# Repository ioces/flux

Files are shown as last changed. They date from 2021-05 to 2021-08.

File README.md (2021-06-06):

# Flux - a battery powered soldering station for Weller RT tips

This design is currently a work in progress, with the ultimate goal of being a portable soldering station utilising Weller RT tips. The design has two outputs, and will be powered off regular 18 or 36 V power tool lithium ion battery packs. It will support all RT tips from the RTP, RTM at RTU series.

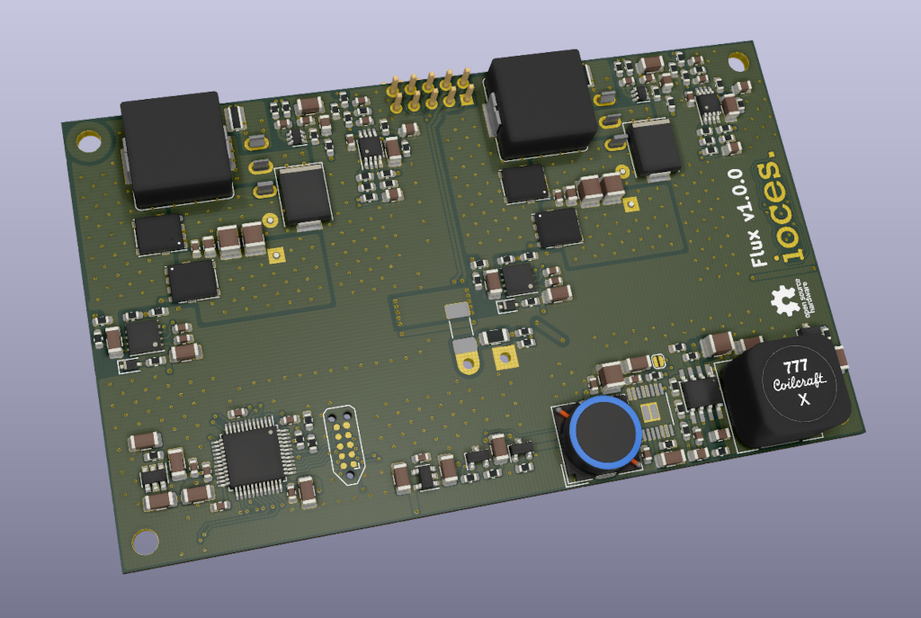
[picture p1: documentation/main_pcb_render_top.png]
Rendering of the Flux PCB from the top


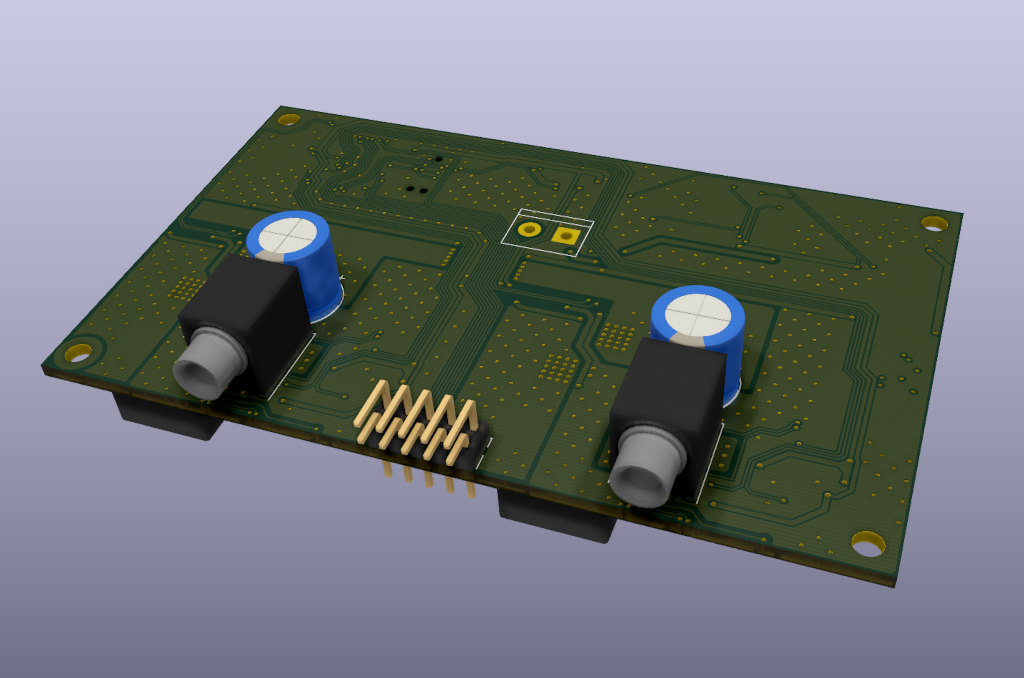
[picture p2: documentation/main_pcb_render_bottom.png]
Rendering of the Flux PCB from the bottom


## Current status

Flux is still a work in progress, and has just made it to the PCA prototyping stage:

- [x] Design
- [x] Schematic capture
- [x] PCB layout of v1.0.0
- [x] Prototype PCB/stencil ordered
- [x] BOM generation
- [x] Part ordering
- [ ] Documentation
- [ ] Prototype assembly
- [ ] Firmware development
- [ ] Prototype testing
- [ ] Enclosure design

## License

This project is licensed under two separate licenses. The hardware design and documentation for this project is licensed under the [CERN Open Hardware Licence Version 2 - Strongly Reciprocal](https://ohwr.org/cern_ohl_s_v2.txt) (CERN-OHL-S-2.0). The software and firmware source code for the project is licensed under the [GNU General Public License Version 3](https://www.gnu.org/licenses/gpl-3.0.txt) (GPL-3.0-only).

Further details can be found in the [license file](LICENSE.md).

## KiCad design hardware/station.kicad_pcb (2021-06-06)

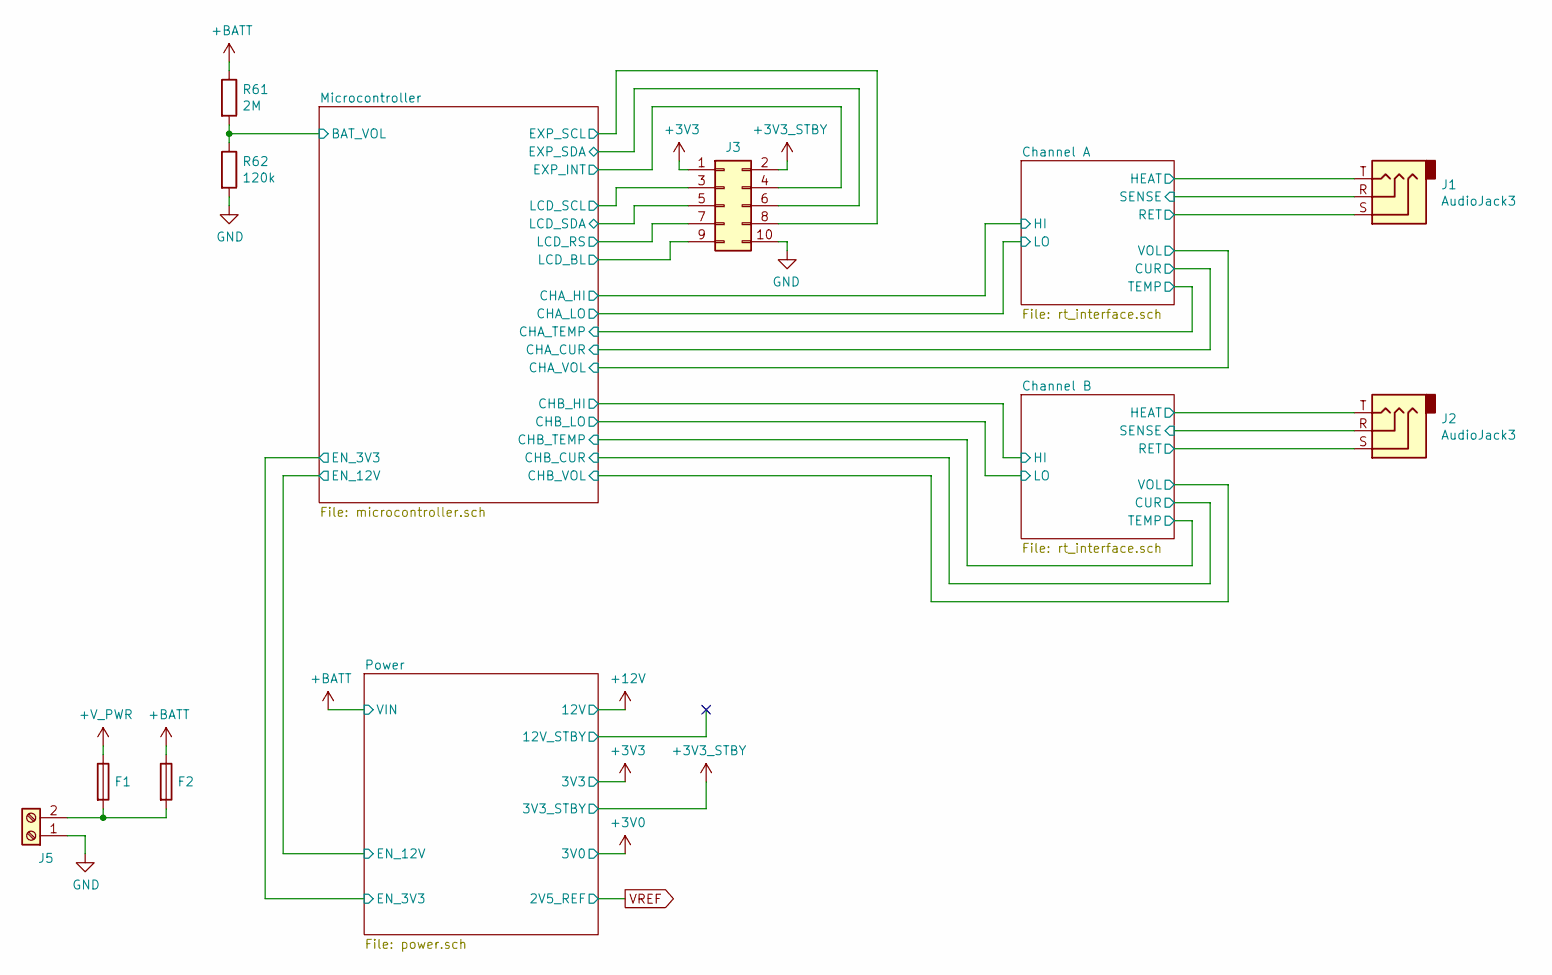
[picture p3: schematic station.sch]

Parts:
F1: Fuse; Fuse_2410; Part Number CB61F15A-TR2
F2: Fuse; Fuse_1206_3216Metric; Part Number C1F 375
J1, J2: AudioJack3; Jack_3.5mm_Adam_Tech_ASJ-125-3; Part Number ASJ-125-3
J3: Conn_02x05_Odd_Even; PinHeader_2x05_P2.54mm_BoardEdge; Part Number 10129382-910002BLF
J5: Screw_Terminal_01x02; TerminalBlock_bornier-2_P5.08mm; Part Number TB004-508-02BE
R61: 2M; R_0603_1608Metric; Tolerance 1%; Part Number ERJ-3EKF2004V
R62: 120k; R_0603_1608Metric; Tolerance 1%; Part Number RMCF0603FT120K

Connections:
+3V3: J3.1; also elsewhere on the board
+3V3_STBY: J3.2; also elsewhere on the board
+BATT: F2.1, R61.1; also elsewhere on the board
+V_PWR: F1.1; also elsewhere on the board
/Channel A/HEAT: J1.T; also elsewhere on the board
/Channel A/RET: J1.S; also elsewhere on the board
/Channel A/SENSE: J1.R; also elsewhere on the board
/Channel B/HEAT: J2.T; also elsewhere on the board
/Channel B/RET: J2.S; also elsewhere on the board
/Channel B/SENSE: J2.R; also elsewhere on the board
/Microcontroller/BAT_VOL: R61.2, R62.1; also elsewhere on the board
/Microcontroller/EXP_INT: J3.4; also elsewhere on the board
/Microcontroller/EXP_SCL: J3.8; also elsewhere on the board
/Microcontroller/EXP_SDA: J3.6; also elsewhere on the board
/Microcontroller/LCD_BL: J3.9; also elsewhere on the board
/Microcontroller/LCD_RS: J3.7; also elsewhere on the board
/Microcontroller/LCD_SCL: J3.3; also elsewhere on the board
/Microcontroller/LCD_SDA: J3.5; also elsewhere on the board
GND: J3.10, J5.1, R62.2; also elsewhere on the board
unnamed: F1.2, F2.2, J5.2

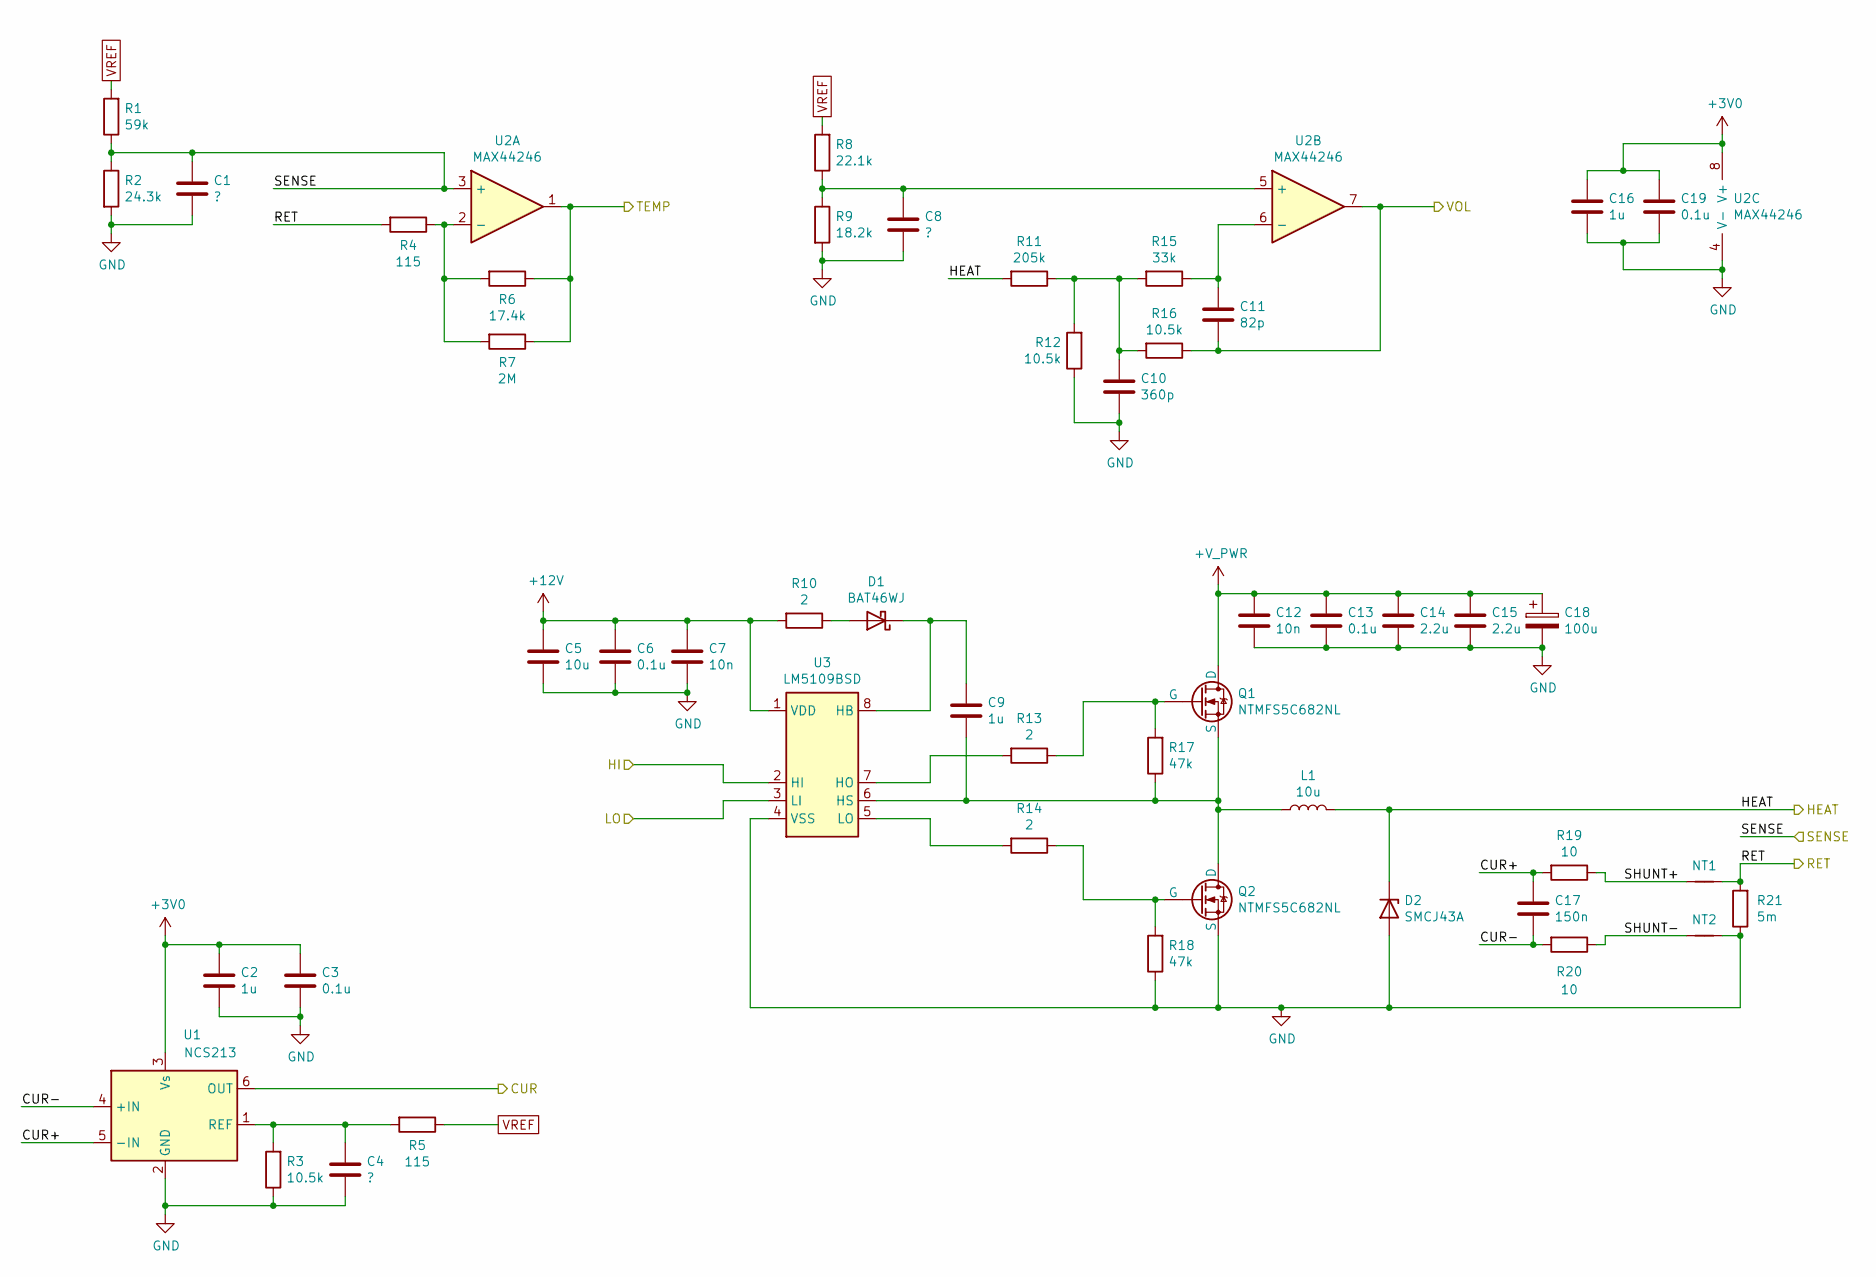
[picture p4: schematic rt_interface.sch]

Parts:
C1, C4, C8: ?; C_0805_2012Metric
C2, C9, C16: 1u; C_1206_3216Metric; Voltage Rating 25 V; Tolerance 10%; Part Number C1206C105K3RACAUTO
C3, C6, C19: 0.1u; C_0603_1608Metric; Voltage Rating 35 V; Tolerance 10%; Part Number GMK107B7104KAHT
C5: 10u; C_1206_3216Metric; Voltage Rating 35 V; Tolerance 10%; Part Number GMK316AB7106KL-TR
C7, C12: 10n; C_0603_1608Metric; Voltage Rating 100 V; Tolerance 10%; Part Number C1608X7R2A103K080AA
C10: 360p; C_0603_1608Metric; Voltage Rating 50 V; Tolerance 5%; Part Number C0603C361J5GAC7867
C11: 82p; C_0603_1608Metric; Voltage Rating 50 V; Tolerance 5%; Part Number C0603C820J5GACTU
C13: 0.1u; C_0805_2012Metric; Voltage Rating 100 V; Tolerance 10%; Part Number 885012207128
C14, C15: 2.2u; C_1210_3225Metric; Voltage Rating 100 V; Tolerance 10%; Part Number HMK325B7225KM-T
C17: 150n; C_0603_1608Metric; Voltage Rating 25 V; Tolerance 10%; Part Number 885012206072
C18: 100u; CP_Radial_D10.0mm_P5.00mm; Voltage Rating 63 V; Tolerance 20%; Part Number 63YXJ100M10X12.5
D1: BAT46WJ; D_SOD-323F; Part Number BAT46WJF
D2: SMCJ43A; D_SMC; Part Number SMCJ43A
L1: 10u; L_Bourns_SRP1265C; Part Number SRP1265C-100M
NT1, NT2: Net-Tie_2; NetTie-2_SMD_Pad0.2mm
Q1, Q2: NTMFS5C682NL; ONSemi_SO-8FL_488AA_Fill; Part Number NTMFS5C682NL
R1: 59k; R_0603_1608Metric; Tolerance 1%; Part Number RMCF0603FT59K0
R2: 24.3k; R_0603_1608Metric; Tolerance 1%; Part Number RMCF0603FT24K3
R3, R12, R16: 10.5k; R_0603_1608Metric; Tolerance 1%; Part Number RMCF0603FT10K5
R4, R5: 115; R_0603_1608Metric; Tolerance 1%; Part Number RMCF0603FT115R
R6: 17.4k; R_0603_1608Metric; Tolerance 1%; Part Number RMCF0603FT17K4
R7: 2M; R_0603_1608Metric; Tolerance 1%; Part Number ERJ-3EKF2004V
R8: 22.1k; R_0603_1608Metric; Tolerance 1%; Part Number RMCF0603FT22K1
R9: 18.2k; R_0603_1608Metric; Tolerance 1%; Part Number RMCF0603FT18K2
R10, R13, R14: 2; R_0603_1608Metric; Tolerance 5%; Part Number ERJ-PA3J2R0V
R11: 205k; R_0603_1608Metric; Tolerance 1%; Part Number RMCF0603FT205K
R15: 33k; R_0603_1608Metric; Tolerance 1%; Part Number CR0603-FX-3302ELF
R17, R18: 47k; R_0603_1608Metric; Tolerance 5%; Part Number CR0603-JW-473ELF
R19, R20: 10; R_0603_1608Metric; Tolerance 1%; Part Number CR0603-FX-10R0ELF
R21: 5m; R_0612_1632Metric; Tolerance 1%; Part Number CSRF0612FT5L00
U1: NCS213; SOT-363_SC-70-6; Part Number NCS213RSQT2G
U2: MAX44246; MSOP-8_3x3mm_P0.65mm; Part Number MAX44246AUA+
U3: LM5109BSD; WSON-8_4x4mm_P0.8mm; Part Number LM5109BSD/NOPB

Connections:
+3V0: C2.1, C3.1, C16.1, C19.1, U1.3 (Vs), U2.8 (V+); also elsewhere on the board
+12V: C5.1, C6.1, C7.1, R10.2, U3.1 (VDD); also elsewhere on the board
+V_PWR: C12.1, C13.1, C14.1, C15.1, C18.1, Q1.5 (D); also elsewhere on the board
/Channel A/CUR+: C17.1, R19.2, U1.5 (-IN)
/Channel A/CUR-: C17.2, R20.2, U1.4 (+IN)
/Channel A/HEAT: D2.1 (K), L1.2, R11.2; also elsewhere on the board
/Channel A/RET: NT1.2, R4.2, R21.2; also elsewhere on the board
/Channel A/SENSE: C1.2, R1.1, R2.1, U2.3 (+); also elsewhere on the board
/Channel A/SHUNT+: NT1.1, R19.1
/Channel A/SHUNT-: NT2.1, R20.1
/Microcontroller/CHA_CUR: U1.6 (OUT); also elsewhere on the board
/Microcontroller/CHA_HI: U3.2 (HI); also elsewhere on the board
/Microcontroller/CHA_LO: U3.3 (LI); also elsewhere on the board
/Microcontroller/CHA_TEMP: R6.1, R7.1, U2.1; also elsewhere on the board
/Microcontroller/CHA_VOL: C11.2, R16.1, U2.7; also elsewhere on the board
GND: C1.1, C2.2, C3.2, C4.1, C5.2, C6.2, C7.2, C8.1, C10.2, C12.2, C13.2, C14.2, C15.2, C16.2, C18.2, C19.2, D2.2 (A), NT2.2, Q2.1 (S), Q2.2 (S), Q2.3 (S), R2.2, R3.1, R9.2, R12.1, R18.1, R21.1, U1.2 (GND), U2.4 (V-), U3.4 (VSS), U3.9 (VSS); also elsewhere on the board
unnamed: C4.2, R3.2, R5.2, U1.1 (REF)
unnamed: C8.2, R8.1, R9.1, U2.5 (+)
unnamed: C9.1, L1.1, Q1.1 (S), Q1.2 (S), Q1.3 (S), Q2.5 (D), R17.1, U3.6 (HS)
unnamed: C9.2, D1.1 (K), U3.8 (HB)
unnamed: C10.1, R11.1, R12.2, R15.2, R16.2
unnamed: C11.1, R15.1, U2.6 (-)
unnamed: D1.2 (A), R10.1
unnamed: Q1.4 (G), R13.1, R17.2
unnamed: Q2.4 (G), R14.1, R18.2
unnamed: R4.1, R6.2, R7.2, U2.2 (-)
unnamed: R13.2, U3.7 (HO)
unnamed: R14.2, U3.5 (LO)
VREF: R1.2, R5.1, R8.2; also elsewhere on the board

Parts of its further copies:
C38, C41, C45: ?; C_0805_2012Metric
C39, C46, C53: 1u; C_1206_3216Metric; Voltage Rating 25 V; Tolerance 10%; Part Number C1206C105K3RACAUTO
C40, C43, C56: 0.1u; C_0603_1608Metric; Voltage Rating 35 V; Tolerance 10%; Part Number GMK107B7104KAHT
C42: 10u; C_1206_3216Metric; Voltage Rating 35 V; Tolerance 10%; Part Number GMK316AB7106KL-TR
C44, C49: 10n; C_0603_1608Metric; Voltage Rating 100 V; Tolerance 10%; Part Number C1608X7R2A103K080AA
C47: 360p; C_0603_1608Metric; Voltage Rating 50 V; Tolerance 5%; Part Number C0603C361J5GAC7867
C48: 82p; C_0603_1608Metric; Voltage Rating 50 V; Tolerance 5%; Part Number C0603C820J5GACTU
C50: 0.1u; C_0805_2012Metric; Voltage Rating 100 V; Tolerance 10%; Part Number 885012207128
C51, C52: 2.2u; C_1210_3225Metric; Voltage Rating 100 V; Tolerance 10%; Part Number HMK325B7225KM-T
C54: 150n; C_0603_1608Metric; Voltage Rating 25 V; Tolerance 10%; Part Number 885012206072
C55: 100u; CP_Radial_D10.0mm_P5.00mm; Voltage Rating 63 V; Tolerance 20%; Part Number 63YXJ100M10X12.5
D3: BAT46WJ; D_SOD-323F; Part Number BAT46WJF
D4: SMCJ43A; D_SMC; Part Number SMCJ43A
L4: 10u; L_Bourns_SRP1265C; Part Number SRP1265C-100M
NT3, NT4: Net-Tie_2; NetTie-2_SMD_Pad0.2mm
Q7, Q8: NTMFS5C682NL; ONSemi_SO-8FL_488AA_Fill; Part Number NTMFS5C682NL
R37: 59k; R_0603_1608Metric; Tolerance 1%; Part Number RMCF0603FT59K0
R38: 24.3k; R_0603_1608Metric; Tolerance 1%; Part Number RMCF0603FT24K3
R39, R48, R52: 10.5k; R_0603_1608Metric; Tolerance 1%; Part Number RMCF0603FT10K5
R40, R41: 115; R_0603_1608Metric; Tolerance 1%; Part Number RMCF0603FT115R
R42: 17.4k; R_0603_1608Metric; Tolerance 1%; Part Number RMCF0603FT17K4
R43: 2M; R_0603_1608Metric; Tolerance 1%; Part Number ERJ-3EKF2004V
R44: 22.1k; R_0603_1608Metric; Tolerance 1%; Part Number RMCF0603FT22K1
R45: 18.2k; R_0603_1608Metric; Tolerance 1%; Part Number RMCF0603FT18K2
R46, R49, R50: 2; R_0603_1608Metric; Tolerance 5%; Part Number ERJ-PA3J2R0V
R47: 205k; R_0603_1608Metric; Tolerance 1%; Part Number RMCF0603FT205K
R51: 33k; R_0603_1608Metric; Tolerance 1%; Part Number CR0603-FX-3302ELF
R53, R54: 47k; R_0603_1608Metric; Tolerance 5%; Part Number CR0603-JW-473ELF
R55, R56: 10; R_0603_1608Metric; Tolerance 1%; Part Number CR0603-FX-10R0ELF
R57: 5m; R_0612_1632Metric; Tolerance 1%; Part Number CSRF0612FT5L00
U8: NCS213; SOT-363_SC-70-6; Part Number NCS213RSQT2G
U9: MAX44246; MSOP-8_3x3mm_P0.65mm; Part Number MAX44246AUA+
U10: LM5109BSD; WSON-8_4x4mm_P0.8mm; Part Number LM5109BSD/NOPB

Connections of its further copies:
+3V0: C39.1, C40.1, C53.1, C56.1, U8.3 (Vs), U9.8 (V+); also elsewhere on the board
+12V: C42.1, C43.1, C44.1, R46.2, U10.1 (VDD); also elsewhere on the board
+V_PWR: C49.1, C50.1, C51.1, C52.1, C55.1, Q7.5 (D); also elsewhere on the board
/Channel B/CUR+: C54.1, R55.2, U8.5 (-IN)
/Channel B/CUR-: C54.2, R56.2, U8.4 (+IN)
/Channel B/HEAT: D4.1 (K), L4.2, R47.2; also elsewhere on the board
/Channel B/RET: NT3.2, R40.2, R57.2; also elsewhere on the board
/Channel B/SENSE: C38.2, R37.1, R38.1, U9.3 (+); also elsewhere on the board
/Channel B/SHUNT+: NT3.1, R55.1
/Channel B/SHUNT-: NT4.1, R56.1
/Microcontroller/CHB_CUR: U8.6 (OUT); also elsewhere on the board
/Microcontroller/CHB_HI: U10.2 (HI); also elsewhere on the board
/Microcontroller/CHB_LO: U10.3 (LI); also elsewhere on the board
/Microcontroller/CHB_TEMP: R42.1, R43.1, U9.1; also elsewhere on the board
/Microcontroller/CHB_VOL: C48.2, R52.1, U9.7; also elsewhere on the board
GND: C38.1, C39.2, C40.2, C41.1, C42.2, C43.2, C44.2, C45.1, C47.2, C49.2, C50.2, C51.2, C52.2, C53.2, C55.2, C56.2, D4.2 (A), NT4.2, Q8.1 (S), Q8.2 (S), Q8.3 (S), R38.2, R39.1, R45.2, R48.1, R54.1, R57.1, U8.2 (GND), U9.4 (V-), U10.4 (VSS), U10.9 (VSS); also elsewhere on the board
unnamed: C41.2, R39.2, R41.2, U8.1 (REF)
unnamed: C45.2, R44.1, R45.1, U9.5 (+)
unnamed: C46.1, L4.1, Q7.1 (S), Q7.2 (S), Q7.3 (S), Q8.5 (D), R53.1, U10.6 (HS)
unnamed: C46.2, D3.1 (K), U10.8 (HB)
unnamed: C47.1, R47.1, R48.2, R51.2, R52.2
unnamed: C48.1, R51.1, U9.6 (-)
unnamed: D3.2 (A), R46.1
unnamed: Q7.4 (G), R49.1, R53.2
unnamed: Q8.4 (G), R50.1, R54.2
unnamed: R40.1, R42.2, R43.2, U9.2 (-)
unnamed: R49.2, U10.7 (HO)
unnamed: R50.2, U10.5 (LO)
VREF: R37.2, R41.1, R44.2; also elsewhere on the board

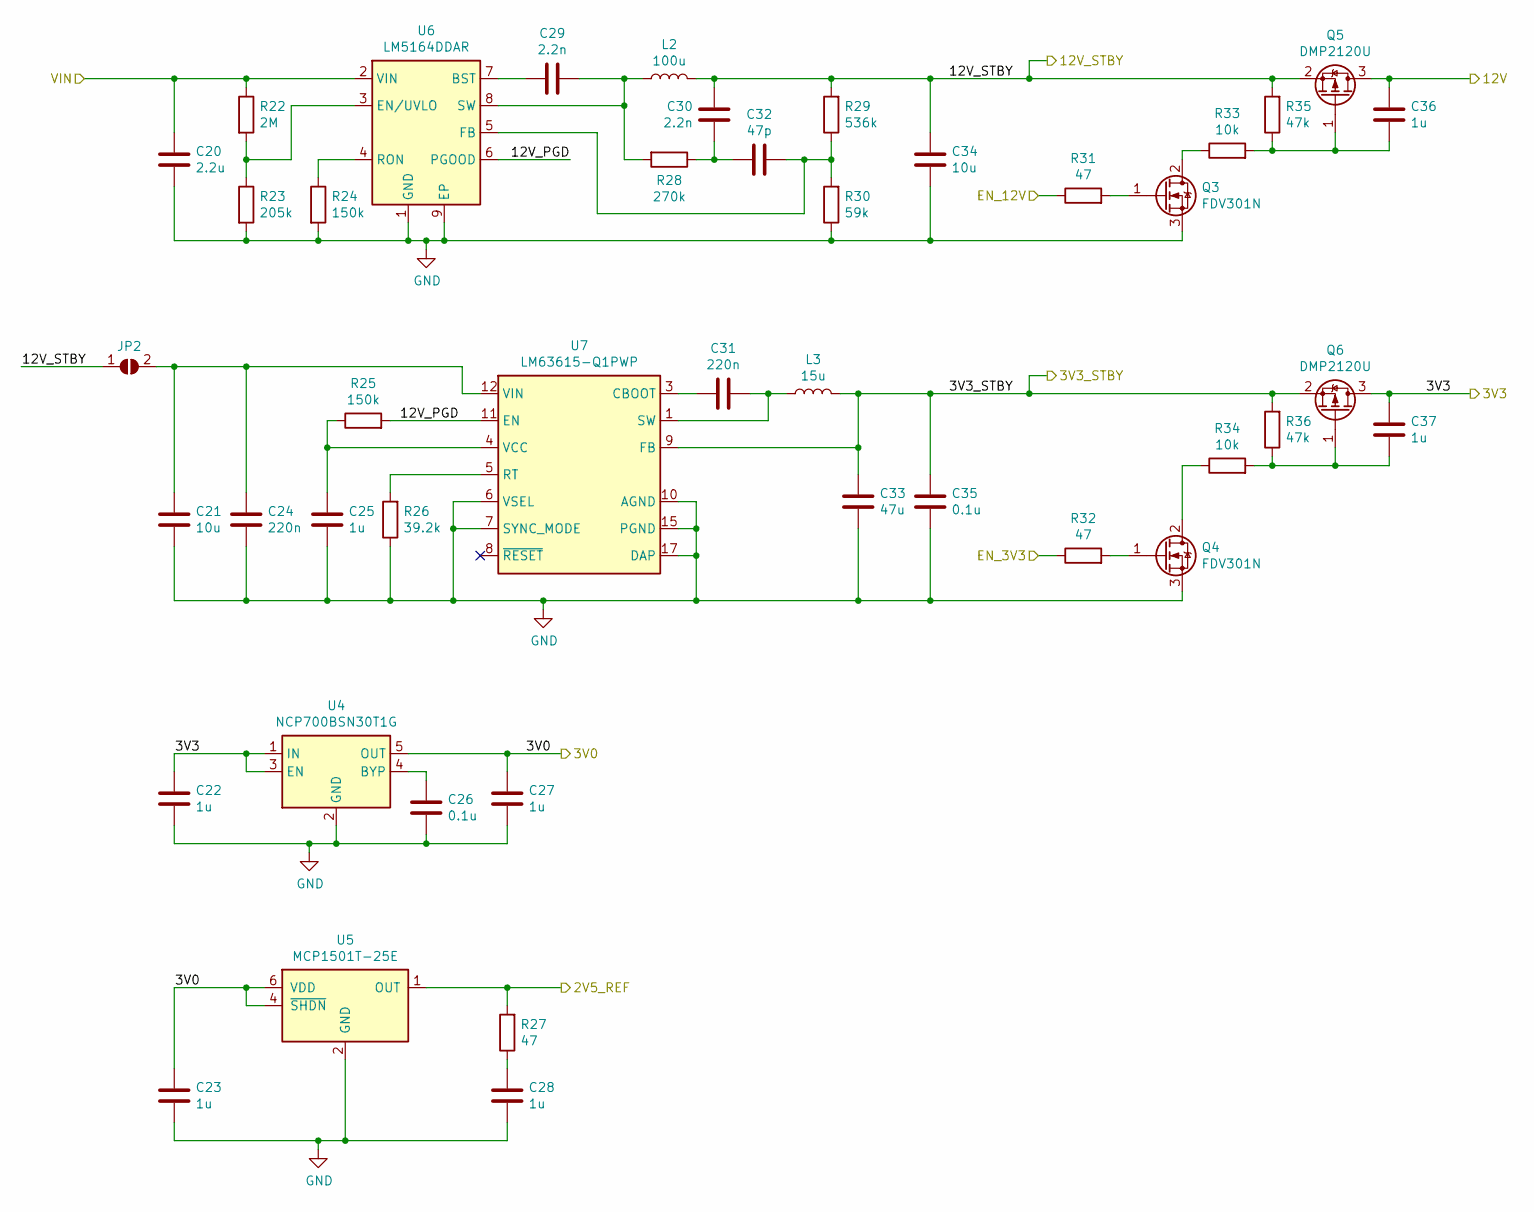
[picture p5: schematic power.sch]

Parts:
C20: 2.2u; C_1210_3225Metric; Voltage Rating 100 V; Tolerance 10%; Part Number HMK325B7225KM-T
C21, C34: 10u; C_1206_3216Metric; Voltage Rating 35 V; Tolerance 10%; Part Number GMK316AB7106KL-TR
C22, C23, C25, C27, C28, C36, C37: 1u; C_1206_3216Metric; Voltage Rating 25 V; Tolerance 10%; Part Number C1206C105K3RACAUTO
C24, C31: 220n; C_0603_1608Metric; Voltage Rating 50 V; Tolerance 10%; Part Number C1608X7R1H224K080AB
C26, C35: 0.1u; C_0603_1608Metric; Voltage Rating 35 V; Tolerance 10%; Part Number GMK107B7104KAHT
C29, C30: 2.2n; C_0805_2012Metric; Voltage Rating 50 V; Tolerance 10%; Part Number C0805C222K5RACTU
C32: 47p; C_0603_1608Metric; Tolerance 5%; Voltage Rating 16V; Part Number 885012006021
C33: 47u; C_1210_3225Metric; Voltage Rating 16 V; Tolerance 10%; Part Number GRM32EC81C476KE15K
JP2: SolderJumper_2_Open; SolderJumper-2_3A
L2: 100u; L_Coilcraft_MSS1210; Part Number MSS1210-104KEB
L3: 15u; L_TDK_SLF10165; Part Number SLF10165T-150M3R13PF
Q3, Q4: FDV301N; SOT-23; Part Number FDV301N
Q5, Q6: DMP2120U; SOT-23; Part Number DMP2120U
R22: 2M; R_0603_1608Metric; Tolerance 1%; Part Number ERJ-3EKF2004V
R23: 205k; R_0603_1608Metric; Tolerance 1%; Part Number RMCF0603FT205K
R24, R25: 150k; R_0603_1608Metric; Tolerance 1%; Part Number RMCF0603FT150K
R26: 39.2k; R_0603_1608Metric; Tolerance 1%; Part Number RMCF0603FT39K2
R27, R31, R32: 47; R_0603_1608Metric; Tolerance 1%; Part Number RMCF0603FT47R0
R28: 270k; R_0603_1608Metric; Tolerance 1%; Part Number RMCF0603FT270K
R29: 536k; R_0603_1608Metric; Tolerance 1%; Part Number RMCF0603FT536K
R30: 59k; R_0603_1608Metric; Tolerance 1%; Part Number RMCF0603FT59K0
R33, R34: 10k; R_0603_1608Metric; Tolerance 5%; Part Number RMCF0603JG10K0
R35, R36: 47k; R_0603_1608Metric; Tolerance 5%; Part Number CR0603-JW-473ELF
U4: NCP700BSN30T1G; SOT-23-5; Part Number NCP700BSN30T1G
U5: MCP1501T-25E; SOT-23-6; Part Number MCP1501T-25E/CHY
U6: LM5164DDAR; TI_SO-PowerPAD-8; Part Number LM5164DDAR
U7: LM63615-Q1PWP; HTSSOP-16-1EP_4.4x5mm_P0.65mm_EP3.4x5mm_Mask2.46x2.31mm; Part Number LM63615-Q1PWP

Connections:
+3V0: C23.1, C27.1, U4.5 (OUT), U5.4 (~SHDN), U5.6 (VDD); also elsewhere on the board
+3V3: C22.1, C37.1, Q6.3 (D), U4.1 (IN), U4.3 (EN); also elsewhere on the board
+3V3_STBY: C33.1, C35.1, L3.2, Q6.2 (S), R36.2, U7.9 (FB); also elsewhere on the board
+12V: C36.1, Q5.3 (D); also elsewhere on the board
+BATT: C20.1, R22.1, U6.2 (VIN); also elsewhere on the board
/Microcontroller/EN_3V3: R32.1; also elsewhere on the board
/Microcontroller/EN_12V: R31.1; also elsewhere on the board
/Power/12V_PGD: R25.2, U6.6 (PGOOD), U7.11 (EN)
/Power/12V_STBY: C30.2, C34.1, JP2.1 (A), L2.2, Q5.2 (S), R29.2, R35.2
GND: C20.2, C21.2, C22.2, C23.2, C24.2, C25.2, C26.2, C27.2, C28.2, C33.2, C34.2, C35.2, Q3.3 (S), Q4.3 (S), R23.2, R24.2, R26.1, R30.1, U4.2 (GND), U5.2 (GND), U5.3 (GND), U5.5 (GND), U6.1 (GND), U6.9 (EP), U7.6 (VSEL), U7.7 (SYNC_MODE), U7.10 (AGND), U7.15 (PGND), U7.16 (PGND), U7.17 (DAP); also elsewhere on the board
unnamed: C21.1, C24.1, JP2.2 (B), U7.12 (VIN), U7.13 (VIN)
unnamed: C25.1, R25.1, U7.4 (VCC)
unnamed: C26.1, U4.4 (BYP)
unnamed: C28.1, R27.1
unnamed: C29.1, L2.1, R28.2, U6.8 (SW)
unnamed: C29.2, U6.7 (BST)
unnamed: C30.1, C32.1, R28.1
unnamed: C31.1, L3.1, U7.1 (SW), U7.2 (SW)
unnamed: C31.2, U7.3 (CBOOT)
unnamed: C32.2, R29.1, R30.2, U6.5 (FB)
unnamed: C36.2, Q5.1 (G), R33.2, R35.1
unnamed: C37.2, Q6.1 (G), R34.2, R36.1
unnamed: Q3.1 (G), R31.2
unnamed: Q3.2 (D), R33.1
unnamed: Q4.1 (G), R32.2
unnamed: Q4.2 (D), R34.1
unnamed: R22.2, R23.1, U6.3 (EN/UVLO)
unnamed: R24.1, U6.4 (RON)
unnamed: R26.2, U7.5 (RT)
VREF: R27.2, U5.1 (OUT); also elsewhere on the board

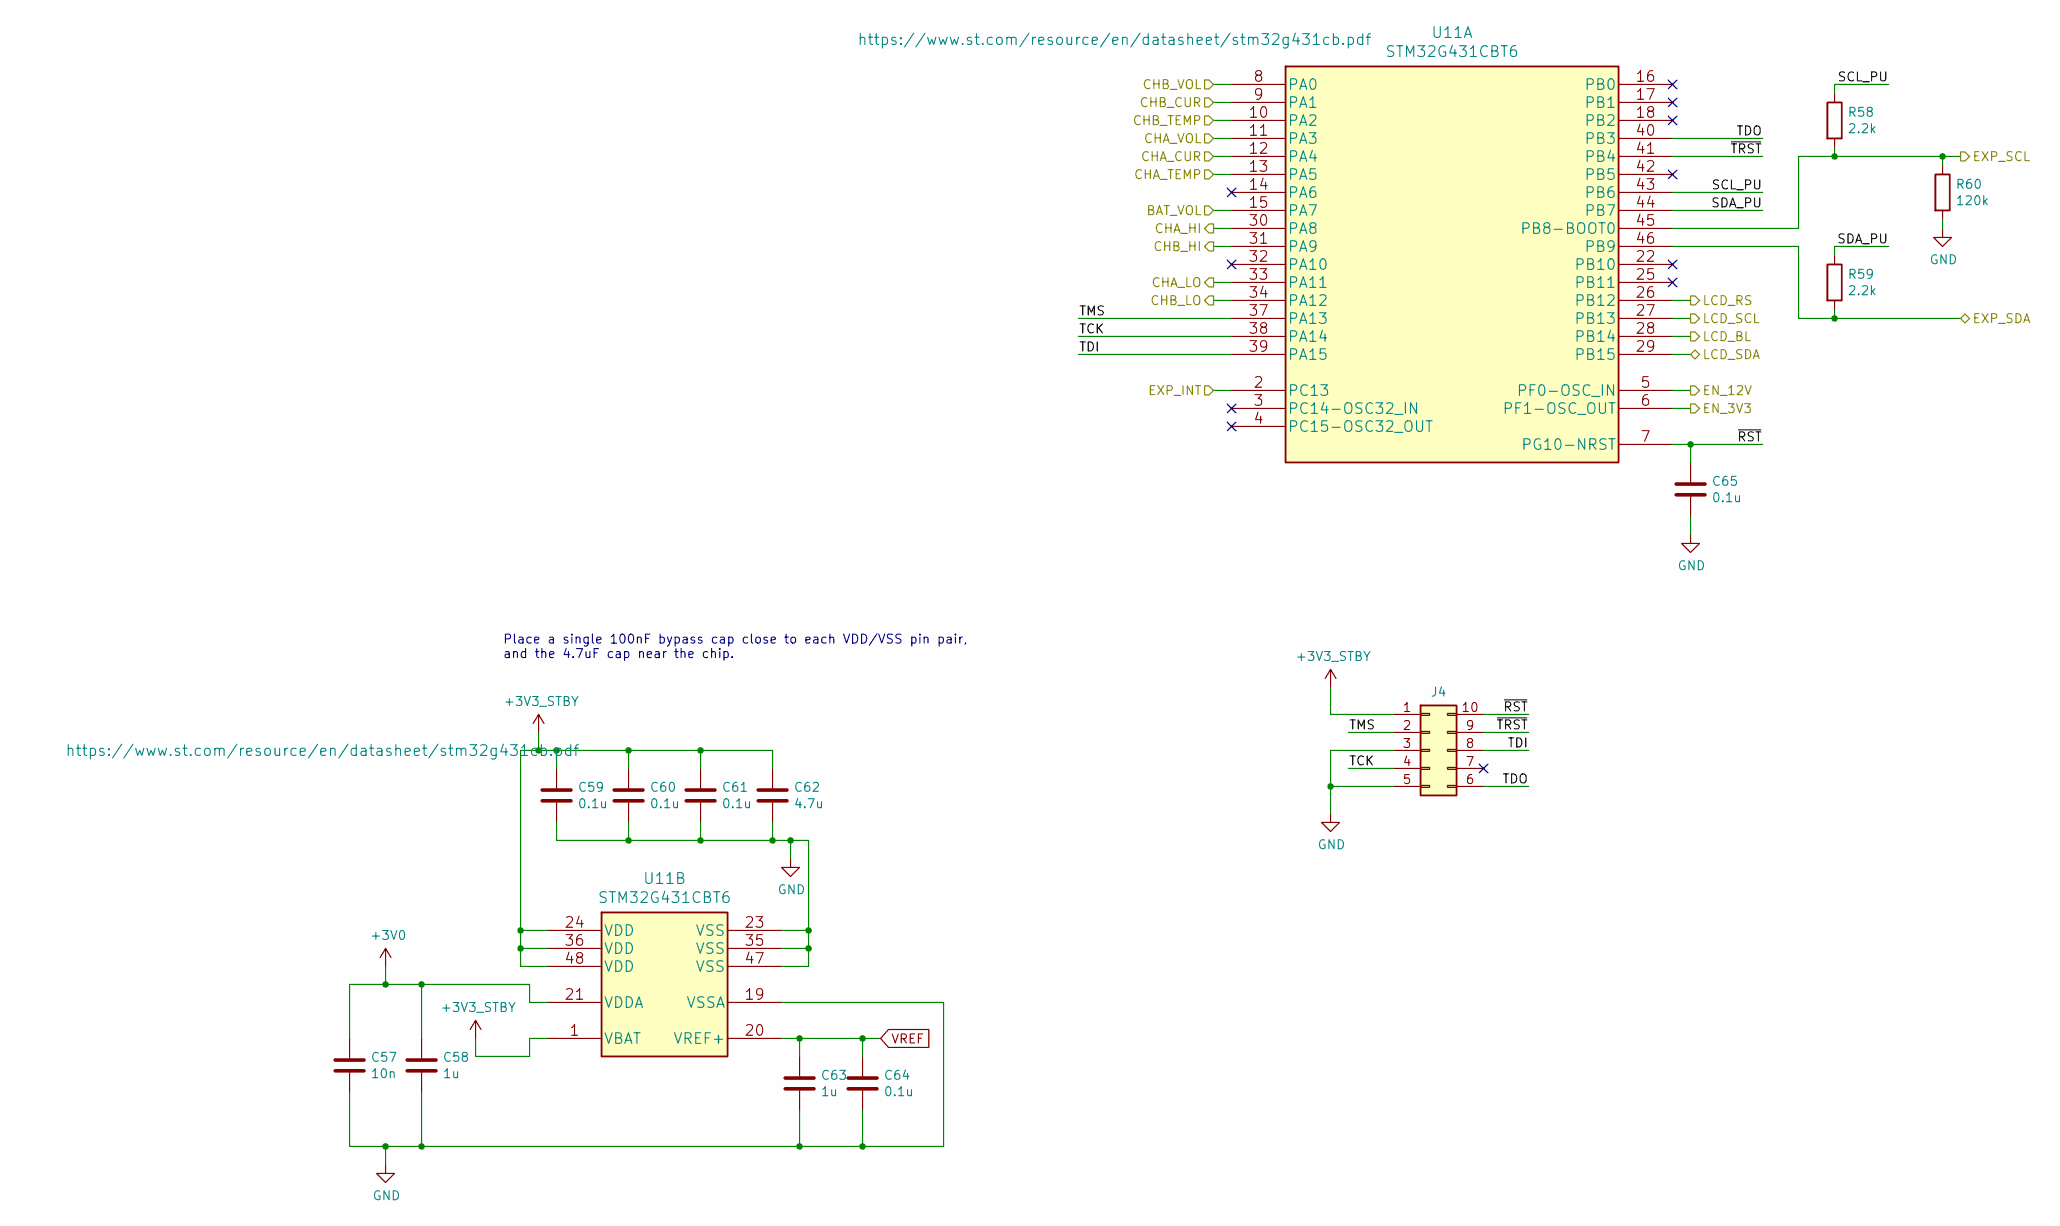
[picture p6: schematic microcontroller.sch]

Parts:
C57: 10n; C_0603_1608Metric; Voltage Rating 100 V; Tolerance 10%; Part Number C1608X7R2A103K080AA
C58, C63: 1u; C_1206_3216Metric; Voltage Rating 25 V; Tolerance 10%; Part Number C1206C105K3RACAUTO
C59, C60, C61, C64, C65: 0.1u; C_0603_1608Metric; Voltage Rating 35 V; Tolerance 10%; Part Number GMK107B7104KAHT
C62: 4.7u; C_1206_3216Metric; Voltage Rating 25 V; Tolerance 10%; Part Number CL31B475KAHNFNE
J4: Conn_02x05_Counter_Clockwise; Tag-Connect_TC2050-IDC-NL_2x05_P1.27mm_Vertical
R58, R59: 2.2k; R_0603_1608Metric; Tolerance 5%; Part Number RMCF0603JT2K20
R60: 120k; R_0603_1608Metric; Tolerance 1%; Part Number RMCF0603FT120K
U11: STM32G431CBT6; LQFP-48_7x7mm_P0.5mm; Part Number STM32G431CBT6

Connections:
+3V0: C57.1, C58.1, U11.21 (VDDA); also elsewhere on the board
+3V3_STBY: C59.1, C60.1, C61.1, C62.1, J4.1, U11.1 (VBAT), U11.24 (VDD), U11.36 (VDD), U11.48 (VDD); also elsewhere on the board
/Microcontroller/BAT_VOL: U11.15 (PA7); also elsewhere on the board
/Microcontroller/CHA_CUR: U11.12 (PA4); also elsewhere on the board
/Microcontroller/CHA_HI: U11.30 (PA8); also elsewhere on the board
/Microcontroller/CHA_LO: U11.33 (PA11); also elsewhere on the board
/Microcontroller/CHA_TEMP: U11.13 (PA5); also elsewhere on the board
/Microcontroller/CHA_VOL: U11.11 (PA3); also elsewhere on the board
/Microcontroller/CHB_CUR: U11.9 (PA1); also elsewhere on the board
/Microcontroller/CHB_HI: U11.31 (PA9); also elsewhere on the board
/Microcontroller/CHB_LO: U11.34 (PA12); also elsewhere on the board
/Microcontroller/CHB_TEMP: U11.10 (PA2); also elsewhere on the board
/Microcontroller/CHB_VOL: U11.8 (PA0); also elsewhere on the board
/Microcontroller/EN_3V3: U11.6 (PF1-OSC_OUT); also elsewhere on the board
/Microcontroller/EN_12V: U11.5 (PF0-OSC_IN); also elsewhere on the board
/Microcontroller/EXP_INT: U11.2 (PC13); also elsewhere on the board
/Microcontroller/EXP_SCL: R58.2, R60.1, U11.45 (PB8-BOOT0); also elsewhere on the board
/Microcontroller/EXP_SDA: R59.2, U11.46 (PB9); also elsewhere on the board
/Microcontroller/LCD_BL: U11.28 (PB14); also elsewhere on the board
/Microcontroller/LCD_RS: U11.26 (PB12); also elsewhere on the board
/Microcontroller/LCD_SCL: U11.27 (PB13); also elsewhere on the board
/Microcontroller/LCD_SDA: U11.29 (PB15); also elsewhere on the board
/Microcontroller/SCL_PU: R58.1, U11.43 (PB6)
/Microcontroller/SDA_PU: R59.1, U11.44 (PB7)
/Microcontroller/TCK: J4.4, U11.38 (PA14)
/Microcontroller/TDI: J4.8, U11.39 (PA15)
/Microcontroller/TDO: J4.6, U11.40 (PB3)
/Microcontroller/TMS: J4.2, U11.37 (PA13)
/Microcontroller/~RST: C65.1, J4.10, U11.7 (PG10-NRST)
/Microcontroller/~TRST: J4.9, U11.41 (PB4)
GND: C57.2, C58.2, C59.2, C60.2, C61.2, C62.2, C63.2, C64.2, C65.2, J4.3, J4.5, R60.2, U11.19 (VSSA), U11.23 (VSS), U11.35 (VSS), U11.47 (VSS); also elsewhere on the board
VREF: C63.1, C64.1, U11.20 (VREF+); also elsewhere on the board

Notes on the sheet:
Place a single 100nF bypass cap close to each VDD/VSS pin pair, and the 4.7uF cap near the chip.

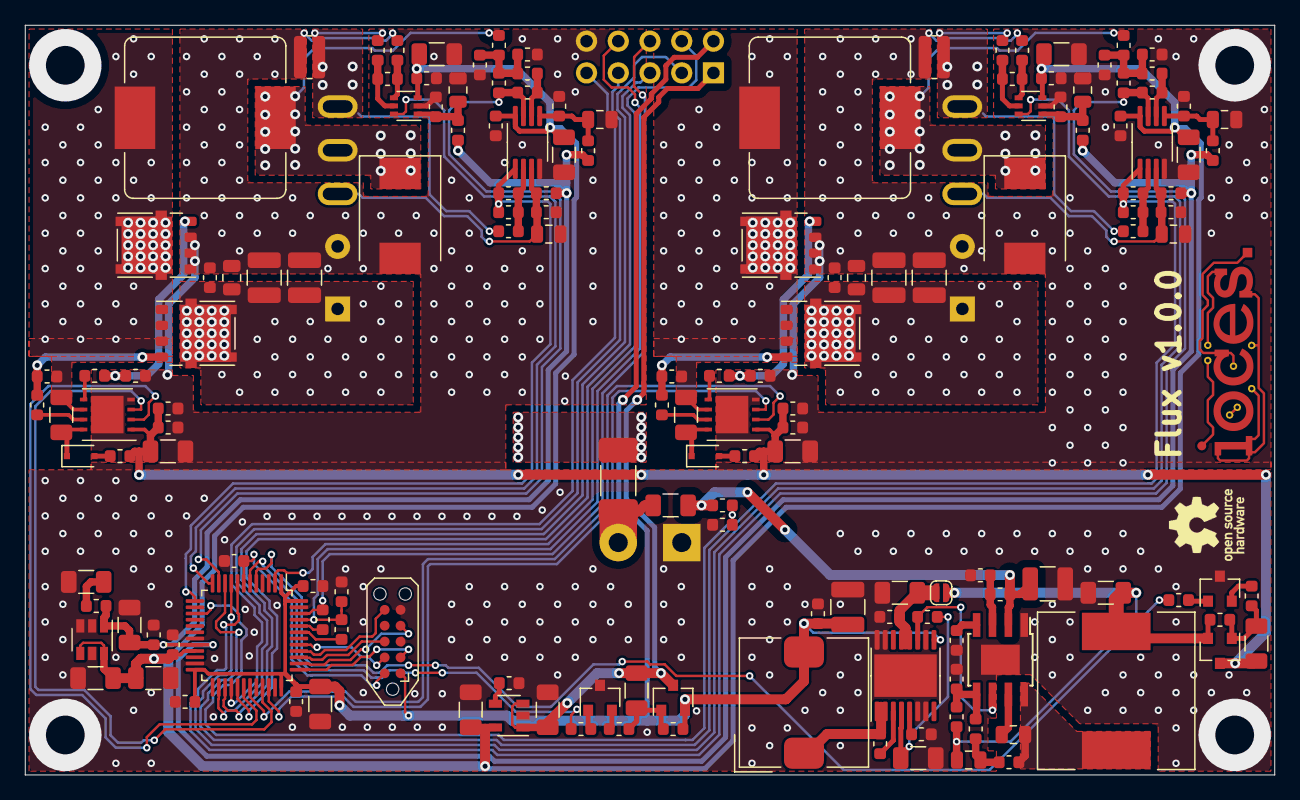
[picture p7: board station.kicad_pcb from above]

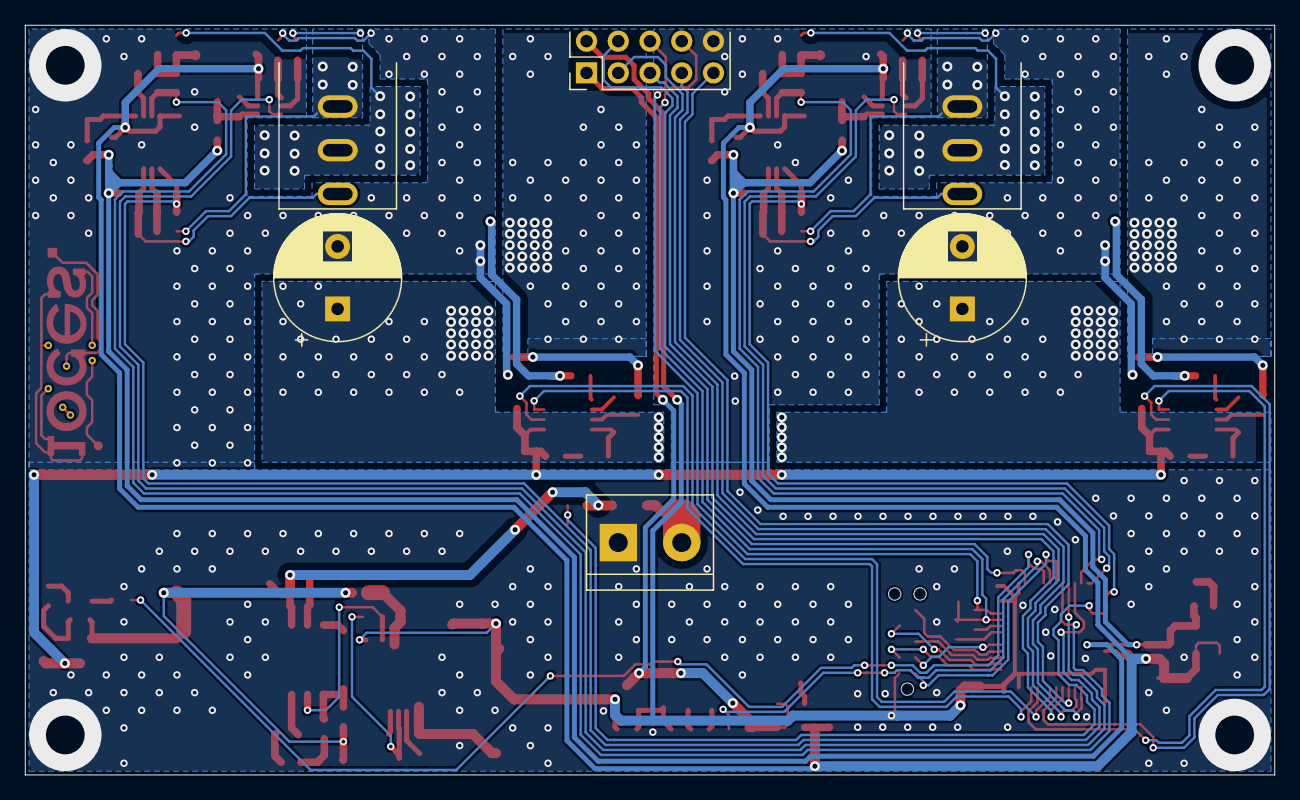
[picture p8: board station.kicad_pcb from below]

Board: 2 copper layers, 100.0 x 60.0 mm, 167 parts (10 on the bottom side), 96 nets.

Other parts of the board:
Ref**: Val**; IocesLogo

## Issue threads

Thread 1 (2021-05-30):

Footprint for 5.08mm pitch terminal block is too small

m-schubert, 2021-05-30:
The 5.08mm terminal block at J5 has a courtyard size of 10.5 x 8.0 mm. It is using the footprint `TerminalBlock:TerminalBlock_bornier-2_P5.08mm` from the KiCAD libraries. On looking for actual terminal blocks with a 15 A+ current rating, I couldn't find any that small.

For now, I'll suggest a bigger component that should still fit, but at some point I should update the footprint (and 3D model).

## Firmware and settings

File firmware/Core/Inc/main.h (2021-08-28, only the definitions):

#define EXP_INT_Pin GPIO_PIN_13
#define EXP_INT_GPIO_Port GPIOC
#define CHB_VOL_Pin GPIO_PIN_0
#define CHB_VOL_GPIO_Port GPIOA
#define CHB_CUR_Pin GPIO_PIN_1
#define CHB_CUR_GPIO_Port GPIOA
#define CHB_TEMP_Pin GPIO_PIN_2
#define CHB_TEMP_GPIO_Port GPIOA
#define CHA_VOL_Pin GPIO_PIN_3
#define CHA_VOL_GPIO_Port GPIOA
#define CHA_CUR_Pin GPIO_PIN_4
#define CHA_CUR_GPIO_Port GPIOA
#define CHA_TEMP_Pin GPIO_PIN_5
#define CHA_TEMP_GPIO_Port GPIOA
#define BAT_VOL_Pin GPIO_PIN_7
#define BAT_VOL_GPIO_Port GPIOA
#define LCD_RS_Pin GPIO_PIN_12
#define LCD_RS_GPIO_Port GPIOB
#define LCD_SCL_Pin GPIO_PIN_13
#define LCD_SCL_GPIO_Port GPIOB
#define LCD_BL_Pin GPIO_PIN_14
#define LCD_BL_GPIO_Port GPIOB
#define LCD_SDA_Pin GPIO_PIN_15
#define LCD_SDA_GPIO_Port GPIOB
#define CHA_HI_Pin GPIO_PIN_8
#define CHA_HI_GPIO_Port GPIOA
#define CHB_HI_Pin GPIO_PIN_9
#define CHB_HI_GPIO_Port GPIOA
#define CHA_LO_Pin GPIO_PIN_11
#define CHA_LO_GPIO_Port GPIOA
#define CHB_LO_Pin GPIO_PIN_12
#define CHB_LO_GPIO_Port GPIOA
#define SCL_PU_Pin GPIO_PIN_6
#define SCL_PU_GPIO_Port GPIOB
#define SDA_PU_Pin GPIO_PIN_7
#define SDA_PU_GPIO_Port GPIOB

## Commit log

2020-12-05 First commit of current work in progress
    [microcontroller.sch, power.sch, rt_interface.sch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]
2020-12-05 Some temporary documentation while I get things in order.
    [Thermocouple.csv]
2021-01-31 Some minor layout changes.
    [station.kicad_pcb]
2021-05-06 Layout almost complete. Just needs a tidy.
    [microcontroller.sch, rt_interface.sch, station.kicad_pcb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]
2021-05-07 Remove some vias to prep for plugin stitching.
    [station.kicad_pcb]
2021-05-16 Add stitching vias
    [station.kicad_pcb]
2021-05-30 Produce manufacturing files
    [station.kicad_pcb]
2021-05-30 Reflect current project status in README
2021-06-06 Update BOM * Datasheets * Manufacturers * Part numbers
    [microcontroller.sch, power.sch, rt_interface.sch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]
2021-08-22 Add I/O expander datasheet and HAL driver manual
    The PCAL6416A is used as an I/O expander, and we're using the HAL of the STM32
    micro. Both datasheets are useful for reference.
2021-08-28 Create a basic firmware skeleton (#2)
    * Add FreeRTOS kernel as a submodule
    * Rearrange firmware, and update licenses
    * Update ignores to include STM32CubeIDE settings

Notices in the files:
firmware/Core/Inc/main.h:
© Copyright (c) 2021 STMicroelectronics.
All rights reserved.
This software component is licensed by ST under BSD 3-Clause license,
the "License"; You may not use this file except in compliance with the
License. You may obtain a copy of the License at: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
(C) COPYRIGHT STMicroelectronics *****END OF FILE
